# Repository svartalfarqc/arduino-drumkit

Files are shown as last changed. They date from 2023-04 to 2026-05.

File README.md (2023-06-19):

# arduino-drumkit
 An electronic drumkit made with an Arduino controller

# Original code
Inspired by this instructable by user anouskadg: https://www.instructables.com/MIDI-Arduino-Drums/
Originally adapted from Jenna deBoisblanc and Spiekenzie Labs initial code
https://www.instructables.com/Arduino-Xylophone/

# Adjustments made to original code:
- Mapping to Ugritone Kult Drums II notes (https://ugritone.com/products/kvlt-drums-ii)
- Added a pushbutton to change pin to note mapping
- Added a pushbutton to change output from midi channel 1 to 16
- Added 4 LEDs to show currently selected midi channel in binary

# Fritzing breadboard
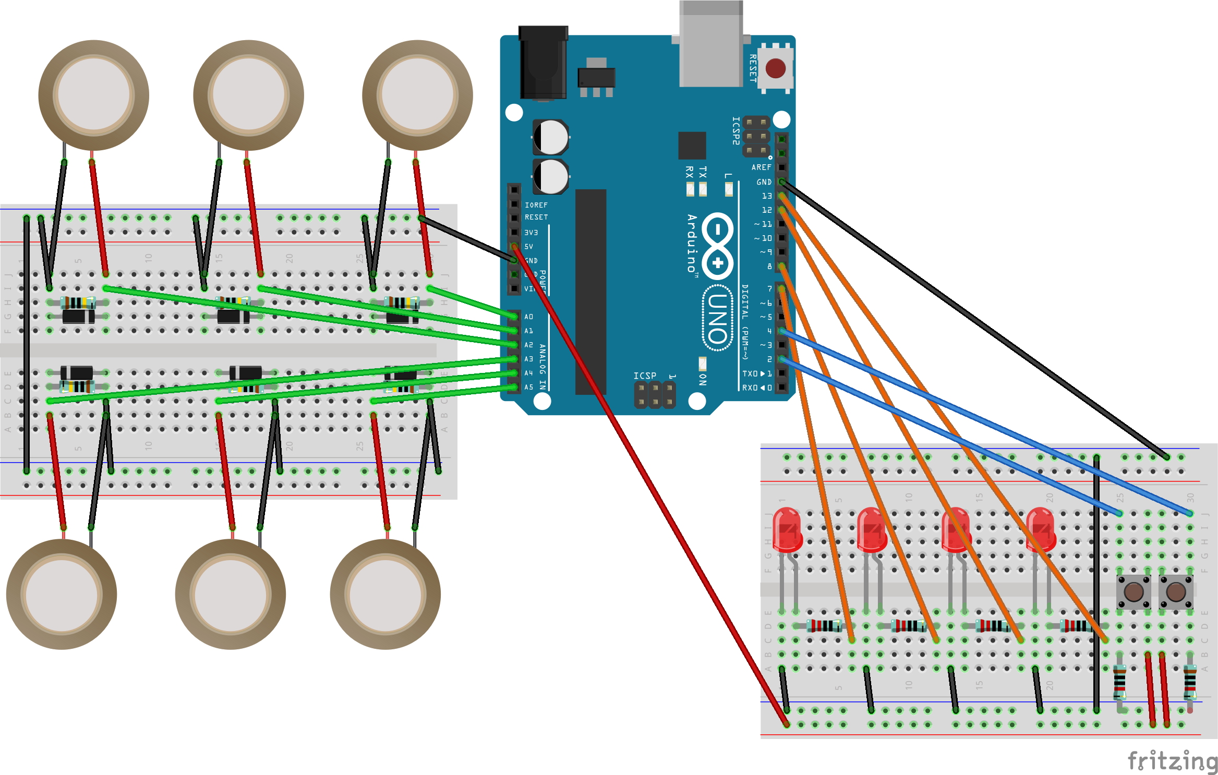
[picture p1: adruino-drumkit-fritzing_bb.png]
Fritzing image


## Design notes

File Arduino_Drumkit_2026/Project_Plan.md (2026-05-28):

# 🥁 Arduino Drumkit Build — Project Plan

**Toy:** First Act Discovery children's drum kit  
**Goal:** MIDI electronic drumkit with interactive LED modes  
**Pace:** ~1 hour per week  
**Estimated total:** 12–15 weeks

---

## What's Inside the Toy

| Component | Count | Notes |
|---|---|---|
| Piezoelectric sensors | 5 | One per drum pad (yellow/orange discs) |
| LED PCBs | 5 | One per pad — small green boards |
| Slider + 2-button module | 1 | In the top-left section of the unit |
| Plastic shell + foam pads | 1 set | Sturdy housing, reusable as-is |

---

## Build Phases

---

### Phase 1 — Piezos + MIDI (Weeks 1–4)
**Goal:** Hit a pad, hear a drum sound on your computer.

**Hardware needed:**
- Arduino Uno (or Nano)
- 1MΩ resistors × 5 (pull-down, one per piezo)
- Optional but recommended: 1N4148 diodes × 5 (protect analog pins from voltage spikes on hard hits)
- USB cable + computer

**Wiring:**
Arduino A0–A4  →  Piezo (+) wires, one per pad
GND            →  Piezo (–) wires, all shared
1MΩ resistor   →  Between each Ax pin and GND

**Software setup:**
- Install [loopMIDI](https://www.tobias-erichsen.de/software/loopmidi.html) (virtual MIDI port, free, Windows)
- Install [Hairless MIDI](https://projectgus.github.io/hairless-midiserial/) (bridges Arduino serial → MIDI)
- Open a DAW (GarageBand, REAPER, etc.) and load a drum VST

**Tasks:**
- [ ] Open all 5 pads, photograph wiring before touching anything
- [ ] Identify and label the 2 wires on each piezo
- [ ] Wire piezos to A0–A4 with 1MΩ pull-downs
- [ ] Upload Phase 1 code
- [ ] Launch loopMIDI + Hairless MIDI, confirm signal reaches DAW
- [ ] Tune `PadCutOff[]` per pad (open Serial Monitor, add a temporary `Serial.print(hitavg)` to see raw values, set cutoff just above idle noise ~50–80)
- [ ] Tune `MaxPlayTime[]` if notes retrigger or cut off early
- [ ] All 5 pads trigger correct MIDI notes reliably

> **Tip:** Set `VelocityFlag = false` while testing so every hit plays at full volume. Turn it back on once the basics work.

---

### Phase 2 — Pad LEDs (Weeks 5–7)
**Goal:** Each pad's LED flashes when that pad is hit.

**Hardware needed:**
- Measure the existing LED PCB forward voltage (multimeter → diode mode) before wiring
- 220Ω resistors (red/green/yellow LEDs) or 150Ω (blue/white LEDs) × 5
- If existing LED PCBs are awkward to reuse: standard 5mm LEDs as replacements

**Wiring:**
Arduino D3, D5, D6, D9, D10  →  LED (+), one per pad (all PWM-capable)
GND                           →  LED (–), all shared
Resistor in series on each    →  Between pin and LED (+)

**Tasks:**
- [ ] Test existing LED PCBs with a 3V coin cell — confirm they light up
- [ ] Wire LEDs to PWM pins with appropriate resistors
- [ ] Add LED flash logic to code (pad hit → LED on for ~25 loop cycles → off)
- [ ] Confirm startup flash (all LEDs blink once on boot = wiring check)
- [ ] All 5 pad LEDs respond correctly to hits

> **Note:** Pins 3, 5, 6, 9, 10 are PWM-capable, which means later you can use `analogWrite()` for brightness control or fade-out effects instead of hard on/off — no rewiring needed.

---

### Phase 3 — Slider + Button Module (Weeks 8–9)
**Goal:** Understand and wire the existing slider + 2-button input. Decide what each does.

**Hardware needed:**
- 10kΩ resistors × 2 (pull-down for each button)
- 3 wires for the potentiometer (5V, GND, wiper → analog pin)

**Wiring:**
Slider wiper   →  A5
Slider ends    →  5V and GND
Button 1       →  D2, with 10kΩ to GND
Button 2       →  D4, with 10kΩ to GND

**Tasks:**
- [ ] Open the slider module, identify the 3 potentiometer pins and 2 button pins
- [ ] Wire slider to A5, read values in Serial Monitor across full travel (expect 0–1023)
- [ ] Wire both buttons, confirm edge detection (LOW→HIGH on press) in Serial Monitor
- [ ] Decide what slider and buttons will control (see Phase 4 ideas below)
- [ ] Add 4 indicator LEDs (pins 7, 8, 12, 13) for binary display if desired

---

### Phase 4 — Projects & Modes (Weeks 10–15)
**Goal:** Use the full hardware for interactive features.

At this point you have: 5 piezos, 5 pad LEDs, a slider, 2 buttons, and optionally 4 indicator LEDs. Here are natural next steps — pick what interests you most:

---

#### Project A — HIT mode (simple, good starting point)
Pad LEDs flash on hit. Buttons cycle MIDI channel. Slider adjusts velocity sensitivity.
- Slider left = subtle, slider right = hot
- 4 indicator LEDs show MIDI channel in binary (0000–1111)

---

#### Project B — LEARN mode (kid-friendly)
A random pad lights up. The player must hit it within a time window.
- Correct hit → score goes up (shown on indicator LEDs), new pad lights
- Wrong pad → correct one blinks as a hint
- Miss timeout → pad blinks rapidly, timer resets
- Slider controls difficulty (timeout: 1–8 seconds)
- Button 2 resets the score

---

#### Project C — FOLLOW mode (rhythm trainer)
Pads light up in a sequence locked to a BPM. Player follows the pattern.
- Slider controls tempo
- Button 1 cycles difficulty (sequence length)
- Button 2 starts/stops

---

#### Project D — FREE PLAY with effects
No game — but LEDs do something musical:
- Pad brightness = velocity (soft hit = dim, hard hit = bright)
- LEDs fade out slowly instead of cutting off (PWM fade loop)
- Slider controls fade speed

---

## Quick Reference — Final Wiring Summary

| Arduino Pin | Connected to |
|---|---|
| A0–A4 | Piezo sensors (one per pad) |
| A5 | Slider wiper |
| D2 | Button 1 |
| D4 | Button 2 |
| D3, D5, D6, D9, D10 | Pad LEDs (PWM) |
| D7, D8, D12, D13 | Indicator LEDs (optional) |
| 5V / GND | Shared power rail |

## Component Checklist

| Component | Value | Qty | Purpose |
|---|---|-----|---|
| Resistor | 1MΩ | 5 | Piezo pull-down |
| Resistor | 10kΩ | 2 | Button pull-down |
| Resistor | 150–220Ω | 9 | LED current limiting |
| Diode | 1N4148 | 5 | Piezo spike protection (optional) |
| LED | 5mm any color | 4 | Indicator LEDs (optional) |

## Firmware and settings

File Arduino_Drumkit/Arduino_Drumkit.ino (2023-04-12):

//Inspired by this instructable by user anouskadg: https://www.instructables.com/MIDI-Arduino-Drums/
//Originally adapted from Jenna deBoisblanc and Spiekenzie Labs initial code
//https://www.instructables.com/Arduino-Xylophone/

// Adjustments made to original code:
// - Mapping to Ugritone Kult Drums II notes (https://ugritone.com/products/kvlt-drums-ii)
// - Added a pushbutton to change pin to note mapping
// - Added a pushbutton to change output from midi channel 1 to 16
// - Added 4 LEDs to show currently selected midi channel in binary

//*******************************************************************************************************************
// User settable variables
//*******************************************************************************************************************
int pinRead;

char pinAssignments[6] ={A0,A1,A2,A3,A4,A5};

// Ugritone Kult Drums II mapping

// Mapping WITHOUT HiHat and Kick drum
byte PadNote1[6] = {
  52, // China1
  48, // Tom1
  43, // Tom4
  38, // Snare
  51, // Ride
  57 // Crash2
  
  // NOTE BANK
  //32, // HiHat
  //36, // Kick
  //41, // Tom5
  //42, // HiHat Medium
  //43, // Tom4
  //44, // HiHat closed
  //45, //Tom3
  //46, // HiHat open
  //47, // Tom2
  //48, // Tom1
  //49, // Crash1
  //50, // Crash1 quick
  //52, // China1
  //53, // Ride quick
  //54, // Ride crash
  //55, // Splash1
  //56, // FxCymbal1
  //58, // Crash2 quick
  //59, // FxCymbal2
  //60, // China2
  };         // MIDI notes from 0 to 127 (Mid C = 60)

// Mapping WITH Kick drum (gougoune mode)
// https://www.je-parle-quebecois.com/lexique/definition/gougoune.html
byte PadNote2[6] = {
  36, // Kick
  36, // Kick
  43, // Tom4
  38, // Snare
  51, // Ride
  57 // Crash2
  };
  
int PadCutOff[6] = {200,200,200,200,200,200};  // Minimum Analog value to cause a drum hit (original code was 400)
int MaxPlayTime[6] = {60,60,60,60,60,60};        // Cycles before a 2nd hit is allowed (original code says 90)
  
int midichannel = 0;      // MIDI channel from 0 to 15 (+1 in "real world")
boolean VelocityFlag  = true;   // Velocity ON (true) or OFF (false)

//*******************************************************************************************************************
// Internal Use Variables
//*******************************************************************************************************************
boolean activePad[6] = {0,0,0,0,0,0};     // Array of flags of pad currently playing
int PinPlayTime[6] = {0,0,0,0,0,0};     // Counter since pad started to play

byte status1;
int pin = 0;     
int hitavg = 0;

// pushbutton variables and constants
const int buttonPin = 2;     // the number of the pushbutton pin
const int altButtonPin = 4;     // the number of the pushbutton pin
const int ledPin1 =  7;      // the number of the LED pin
const int ledPin2 =  8;      // the number of the LED pin
const int ledPin3 =  12;      // the number of the LED pin
const int ledPin4 =  13;      // the number of the LED pin

// pushbutton to select midi channel
int buttonState = 0;
int lastButtonState = 0;
int controlState = 0;

// pushbutton to select "alt" mode (alternate pin mapping) a.k.a. gougoune mode
int altButtonState = 0;
int altLastButtonState = 0;
int altControlState = 0;

/**
  Setup
*/
void setup() 
{
  Serial.begin(115200);   // connect to the serial port 115200
  
  // initialize the LED pins as an output:
  pinMode(ledPin1, OUTPUT);
  pinMode(ledPin2, OUTPUT);
  pinMode(ledPin3, OUTPUT);
  pinMode(ledPin4, OUTPUT);
  // initialize the pushbutton pins as an input:
  pinMode(buttonPin, INPUT);
  pinMode(altButtonPin, INPUT);
}

/**
  Read pushbuttons and adjust LEDs as needed
*/
void readPushButtons(){
  // read the state of the pushbutton value:
  buttonState = digitalRead(buttonPin);
  altButtonState = digitalRead(altButtonPin);
  
  // pushbutton state change
  if (lastButtonState == 0 && buttonState == 1)
  {
    if (controlState == 15)
    {
      controlState = 0;
    }
    else
    {
      controlState += 1;
    };
  }
  lastButtonState = buttonState;

  // alt pushbutton state change
  if (altLastButtonState == 0 && altButtonState == 1)
  {
    if (altControlState == 0)
    {
      altControlState = 1;
    }
    else
    {
      altControlState = 0;
    };
  }
  altLastButtonState = altButtonState;

  // Adjust LEDs to show current pushbutton state
  // There is definitely no more elegant way to do this
  if (controlState == 0) {
    digitalWrite(ledPin1, LOW);
    digitalWrite(ledPin2, LOW);
    digitalWrite(ledPin3, LOW);
    digitalWrite(ledPin4, LOW);
  }
  else if (controlState == 1){
    digitalWrite(ledPin1, LOW);
    digitalWrite(ledPin2, LOW);
    digitalWrite(ledPin3, LOW);
    digitalWrite(ledPin4, HIGH);
  }
  else if (controlState == 2){
    digitalWrite(ledPin1, LOW);
    digitalWrite(ledPin2, LOW);
    digitalWrite(ledPin3, HIGH);
    digitalWrite(ledPin4, LOW);
  }
  else if (controlState == 3){
    digitalWrite(ledPin1, LOW);
    digitalWrite(ledPin2, LOW);
    digitalWrite(ledPin3, HIGH);
    digitalWrite(ledPin4, HIGH);
  }
  else if (controlState == 4){
    digitalWrite(ledPin1, LOW);
    digitalWrite(ledPin2, HIGH);
    digitalWrite(ledPin3, LOW);
    digitalWrite(ledPin4, LOW);
  }
  else if (controlState == 5){
    digitalWrite(ledPin1, LOW);
    digitalWrite(ledPin2, HIGH);
    digitalWrite(ledPin3, LOW);
    digitalWrite(ledPin4, HIGH);
  }
  else if (controlState == 6){
    digitalWrite(ledPin1, LOW);
    digitalWrite(ledPin2, HIGH);
    digitalWrite(ledPin3, HIGH);
    digitalWrite(ledPin4, LOW);
  }
  else if (controlState == 7){
    digitalWrite(ledPin1, LOW);
    digitalWrite(ledPin2, HIGH);
    digitalWrite(ledPin3, HIGH);
    digitalWrite(ledPin4, HIGH);
  }
  else if (controlState == 8){
    digitalWrite(ledPin1, HIGH);
    digitalWrite(ledPin2, LOW);
    digitalWrite(ledPin3, LOW);
    digitalWrite(ledPin4, LOW);
  }
  else if (controlState == 9){
    digitalWrite(ledPin1, HIGH);
    digitalWrite(ledPin2, LOW);
    digitalWrite(ledPin3, LOW);
    digitalWrite(ledPin4, HIGH);
  }
  else if (controlState == 10){
    digitalWrite(ledPin1, HIGH);
    digitalWrite(ledPin2, LOW);
    digitalWrite(ledPin3, HIGH);
    digitalWrite(ledPin4, LOW);
  }
  else if (controlState == 11){
    digitalWrite(ledPin1, HIGH);
    digitalWrite(ledPin2, LOW);
    digitalWrite(ledPin3, HIGH);
    digitalWrite(ledPin4, HIGH);
  }
  else if (controlState == 12){
    digitalWrite(ledPin1, HIGH);
    digitalWrite(ledPin2, HIGH);
    digitalWrite(ledPin3, LOW);
    digitalWrite(ledPin4, LOW);
  }
  else if (controlState == 13){
    digitalWrite(ledPin1, HIGH);
    digitalWrite(ledPin2, HIGH);
    digitalWrite(ledPin3, LOW);
    digitalWrite(ledPin4, HIGH);
  }
  else if (controlState == 14){
    digitalWrite(ledPin1, HIGH);
    digitalWrite(ledPin2, HIGH);
    digitalWrite(ledPin3, HIGH);
    digitalWrite(ledPin4, LOW);
  }
  else if (controlState == 15){
    digitalWrite(ledPin1, HIGH);
    digitalWrite(ledPin2, HIGH);
    digitalWrite(ledPin3, HIGH);
    digitalWrite(ledPin4, HIGH);
  }
}

/**
  Read input pads and send midi signals
*/
void readMidi(){
  for(int pin=0; pin < 6; pin++)                                             
  {
    hitavg = analogRead(pinAssignments[pin]);  

    // read the input pin
    if((hitavg > PadCutOff[pin]))
    {
      if((activePad[pin] == false))
      {
        if(VelocityFlag == true)
        {
          //hitavg = 127 / ((1023 - PadCutOff[pin]) / (hitavg - PadCutOff[pin]));    // With full range (Too sensitive ?)
          hitavg = (hitavg / 8) -1 ;                                                 // Upper range
        }
        else
        {
          hitavg = 127;
        }

        // Set note mapping depending on alt pushbutton state
        if (altControlState == 0)
        {
          MIDI_TX(144,PadNote1[pin],hitavg);
        }
        else
        {
          MIDI_TX(144,PadNote2[pin],hitavg);
        }
        
        PinPlayTime[pin] = 0;
        activePad[pin] = true;
      }
      else
      {
        PinPlayTime[pin] = PinPlayTime[pin] + 1;
      }
    }
    else if((activePad[pin] == true))
    {
      PinPlayTime[pin] = PinPlayTime[pin] + 1;
      if(PinPlayTime[pin] > MaxPlayTime[pin])
      {
        activePad[pin] = false;

        // Set note mapping depending on alt pushbutton state
        if (altControlState == 0)
        {
          MIDI_TX(144,PadNote1[pin],0); 
        }
        else
        {
          MIDI_TX(144,PadNote2[pin],0); 
        }
      }
    }
  } 
}

/**
  Main program
*/
void loop() 
{
  // read pushbuttons and adjust LEDs as needed
  readPushButtons();

  // read input pads and send midi signals
  readMidi();
}

//*******************************************************************************************************************
// Transmit MIDI Message
//*******************************************************************************************************************
void MIDI_TX(byte MESSAGE, byte PITCH, byte VELOCITY) 
{
  midichannel = controlState;
  status1 = MESSAGE + midichannel;
  Serial.write(status1);
  Serial.write(PITCH);
  Serial.write(VELOCITY);
}

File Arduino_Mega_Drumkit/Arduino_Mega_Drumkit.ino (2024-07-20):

// Inspired by this instructable by user anouskadg: https://www.instructables.com/MIDI-Arduino-Drums/
// Originally adapted from Jenna deBoisblanc and Spiekenzie Labs initial code
// https://www.instructables.com/Arduino-Xylophone/

// Adjustments made to original code:
// - Mapping to Ugritone Kult Drums II notes (https://ugritone.com/products/kvlt-drums-ii)
// - Added a pushbutton to change pin to note mapping
// - Added a pushbutton to change output from MIDI channel 1 to 16
// - Added 4 LEDs to show currently selected MIDI channel in binary
// - Added digital inputs for additional button-based triggers
// - Added LED visual effect

//*******************************************************************************************************************
// User settable variables
//*******************************************************************************************************************
const int numAnalogInputs = 15; // Number of analog inputs
const int numDigitalInputs = 3; // Number of digital inputs

const int analogPinAssignments[numAnalogInputs] = {A0, A1, A2, A3, A4, A5, A6, A7, A8, A9, A10, A11, A12, A13, A14}; // Analog pins
const int digitalPinAssignments[numDigitalInputs] = {2, 3, 4}; // Digital pins for additional inputs

// LED PWM pins
//const int ledPins[3] = {9, 10, 11}; // PWM pins for LEDs

// Ugritone Kult Drums II mapping
const byte PadNote[numAnalogInputs + numDigitalInputs] = {
  32, // A0 // Hihat open
  42, // A1 // Hihat closed
  44, // A2 // Hihat pedal
  38, // A3 // Snare
  41, // A4 // Tom5
  51, // A5 // Ride top
  36, // A6 // Kick
  36, // A7 // Kick
  48, // A8 // Tom1
  47, // A9 // Tom2
  45, // A10 // Tom3
  43, // A11 // Tom4
  52, // A12 // China1
  57, // A13 // Crash2
  59, // A14 // Fxcymbal2
  49, // D2 // Crash1
  61, // D3 // China2
  56  // D4 // Fxcymbal1
};

const int PadCutOff[numAnalogInputs] = {200, 200, 200, 200, 200, 200, 200, 200, 200, 200, 200, 200, 200, 200, 200}; // Minimum Analog value to cause a drum hit
const int MaxPlayTime[numAnalogInputs + numDigitalInputs] = {60, 60, 60, 60, 60, 60, 60, 60, 60, 60, 60, 60, 60, 60, 60, 60, 60, 60}; // Cycles before a 2nd hit is allowed

int midichannel = 0; // MIDI channel from 0 to 15 (+1 in "real world")
const boolean VelocityFlag = true; // Velocity ON (true) or OFF (false)

// NOTE BANK
const byte NoteBank[23] = {
  32, // Hihat wideopen
  36, // Kick
  38, // Snare
  41, // Tom5
  42, // HiHat closed
  43, // Tom4
  44, // HiHat pedal
  45, // Tom3
  46, // HiHat open
  47, // Tom2
  48, // Tom1
  49, // Crash1
  50, // Crash1 quick
  51, // Ride top
  52, // China1
  53, // Ride bell
  54, // Ride crash
  55, // Splash1
  56, // FxCymbal1
  57, // Crash2
  58, // Crash2 quick
  59, // FxCymbal2
  61  // China2
};

//*******************************************************************************************************************
// Internal Use Variables
//*******************************************************************************************************************
boolean activePad[numAnalogInputs + numDigitalInputs] = {0};
int PinPlayTime[numAnalogInputs + numDigitalInputs] = {0};

byte status1;
int hitavg = 0;

//unsigned long lastLedUpdate = 0; // Timestamp of the last LED update
//int ledBrightness[3] = {0}; // Brightness levels of LEDs
//int ledFadeDirection[3] = {1, 1, 1}; // Fade direction of LEDs: 1 for increasing, -1 for decreasing

/**
  Setup
*/
void setup() {
  Serial.begin(115200); // connect to the serial port 115200
  
  // Set up digital pins for input
  for (int i = 0; i < numDigitalInputs; i++) {
    pinMode(digitalPinAssignments[i], INPUT_PULLUP);
  }

//   // Set up LED pins for output (add current-limiting resistors to each LED)
//   for (int i = 0; i < 3; i++) {
//     pinMode(ledPins[i], OUTPUT);
//     analogWrite(ledPins[i], 0); // Initialize LEDs to off
//   }

 }

/**
  Read input pads and send MIDI signals
*/
void readMidi() {
  // Read analog inputs
  for (int pin = 0; pin < numAnalogInputs; pin++) {
    hitavg = analogRead(analogPinAssignments[pin]);

    if (hitavg > PadCutOff[pin]) {
      if (!activePad[pin]) {
        if (VelocityFlag) {
          hitavg = (hitavg / 8) - 1; // Upper range
        } else {
          hitavg = 127;
        }

        MIDI_TX(144, PadNote[pin], hitavg);
        PinPlayTime[pin] = 0;
        activePad[pin] = true;
      } else {
        PinPlayTime[pin]++;
      }
    } else if (activePad[pin]) {
      PinPlayTime[pin]++;
      if (PinPlayTime[pin] > MaxPlayTime[pin]) {
        activePad[pin] = false;
        MIDI_TX(144, PadNote[pin], 0);
      }
    }
  }
  
  // Read digital inputs
  for (int i = 0; i < numDigitalInputs; i++) {
    int state = digitalRead(digitalPinAssignments[i]);
    int pinIndex = numAnalogInputs + i; // digital inputs are mapped after analog inputs in PadNote array

    if (state == LOW && !activePad[pinIndex]) { // button pressed
      MIDI_TX(144, PadNote[pinIndex], 100); // Set a more reasonable fixed velocity for digital inputs
      PinPlayTime[pinIndex] = 0;
      activePad[pinIndex] = true;
    } else if (state == HIGH && activePad[pinIndex]) { // button released
      PinPlayTime[pinIndex]++;
      if (PinPlayTime[pinIndex] > MaxPlayTime[pinIndex]) {
        activePad[pinIndex] = false;
        MIDI_TX(144, PadNote[pinIndex], 0);
      }
    }
  }
}

/**
  Update LEDs for a cool visual effect
*/
// void updateLEDs() {
//   unsigned long currentMillis = millis();
  
//   // Update LEDs every 10ms
//   if (currentMillis - lastLedUpdate >= 10) {
//     lastLedUpdate = currentMillis;
    
//     for (int i = 0; i < 3; i++) {
//       ledBrightness[i] += ledFadeDirection[i] * 5;
      
//       // Reverse direction if we hit the end of the brightness range
//       if (ledBrightness[i] <= 0) {
//         ledBrightness[i] = 0;
//         ledFadeDirection[i] = 1;
//       } else if (ledBrightness[i] >= 255) {
//         ledBrightness[i] = 255;
//         ledFadeDirection[i] = -1;
//       }
      
//       analogWrite(ledPins[i], ledBrightness[i]);
//     }
//   }
// }

/**
  Main program
*/
void loop() {
  readMidi();
  //updateLEDs();
}

//*******************************************************************************************************************
// Transmit MIDI Message
//*******************************************************************************************************************
void MIDI_TX(byte MESSAGE, byte PITCH, byte VELOCITY) {
  status1 = MESSAGE + midichannel;
  Serial.write(status1);
  Serial.write(PITCH);
  Serial.write(VELOCITY);
}

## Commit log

2022-07-28 button state
2022-07-29 2 buttons and 4 LEDs
2022-08-21 circuit in fritzing
    [adruino-drumkit-fritzing.fzz, arduino-drumkit-schematics.kicad_pcb, arduino-drumkit-schematics.kicad_sch]
2023-04-12 Updated some comments
    [arduino-drumkit-schematics.kicad_pcb, arduino-drumkit-schematics.kicad_sch]
2024-07-20 Cleanup, extension and LEDs
    Added an extension, cleanup up code.
    Tried to add LEDs, commented out.
2026-05-25 Add Arduino Drumkit sketch and project plan
    Add new Arduino_Drumkit_2026.ino and Project_Plan.md. The sketch implements a 6-pad MIDI drum controller with two LED modes (HIT and LEARN), per-pad LEDs, 4-bit indicator LEDs for channel/score, button handling (mode and alt), velocity support, alternate pad mapping, and serial MIDI transmission. LEARN mode includes target selection, scoring, timeout blinking and reset behavior. Project_Plan.md documents hardware inventory, wiring diagram, button/LED scheme, phased build plan, tuning tips, and future mode ideas to guide assembly and testing.
    [Arduino_Drumkit_2026.ino]
2026-05-26 Restructure project: add Phase1 firmware & plan
    Replace the previous enhanced 6-pad/LED build with a simplified Phase 1 setup: add a new Arduino sketch (Arduino_Drumkit_2026/Arduino_Drumkit_2026.ino) implementing 5 piezo inputs + MIDI, update the project plan for a 5-pad build (Project_Plan.md), and add three photos and a VS Code workspace file. Remove the old nested Arduino_Drumkit_2026/Arduino_Drumkit_2026 firmware and its Project_Plan.md to declutter the repo and focus development on the basic MIDI functionality and early build phases.
    [Arduino_Drumkit_2026.ino]
2026-05-28 Expand Arduino drumkit project plan
    Add detailed wiring, software setup, and step-by-step tasks for the Arduino drumkit project. Introduces piezo wiring (A0–A4, 1MΩ pull-downs), LED wiring (PWM pins), slider/button wiring (A5, D2, D4), and recommended components. Adds Phase-based roadmap (Pad LEDs, Slider+Button module, Projects & Modes) with testing/tuning steps, tips for velocity testing, example project modes (HIT/LEARN/FOLLOW/FREE PLAY), a final wiring quick-reference table, and a component checklist.
